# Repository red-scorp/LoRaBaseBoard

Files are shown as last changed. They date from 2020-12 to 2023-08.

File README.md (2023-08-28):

# LoRaBaseBoard

LoRa Base Board for popular Hoperf's RFM95/96/97/98 modules.

One day I wanted to play with LoRa in sender-receiver setup.
What I have fount there are a lot of SMD-mountable modules available but no modules suitable for common prototyping breadboards.
Here I've tried to create a user friendly way to use commonly available LoRa modules.

## LoRaBaseBoard

Simple adapted board intended to be used with variety of RFM LoRa radio modules and being used for HW prototyping.

Preview:

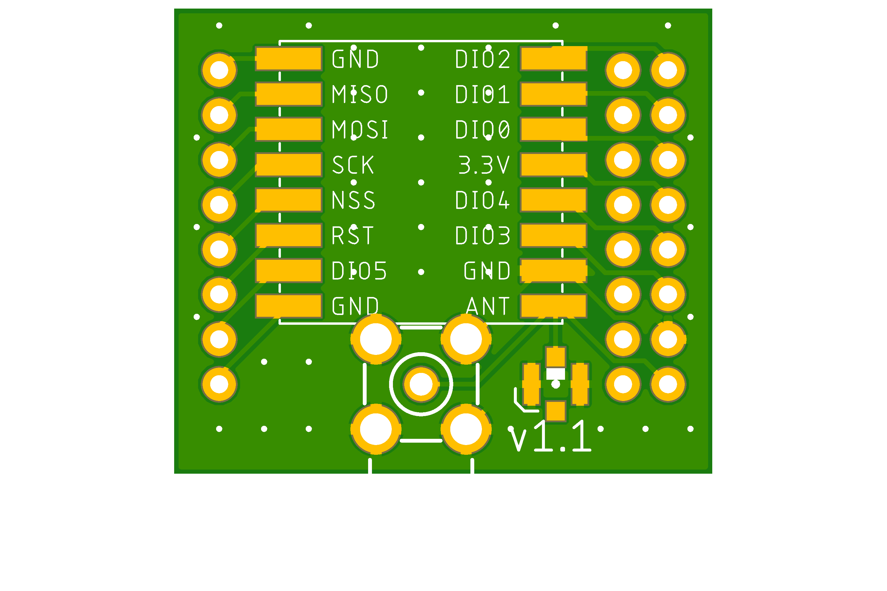
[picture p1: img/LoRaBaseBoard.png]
LoRaBaseBoard preview


[Schematics in PDF format](doc/LoRaBaseBoard.pdf)

Features:

- generic board for RFM radio modules
- compatible with common breadboards and prototyping boards (2.54mm raster)

CAM files are available.

## LoRaAdapter

This adapter board is meant to be a drop-in replacement for NRF24L01 modules.

Preview:

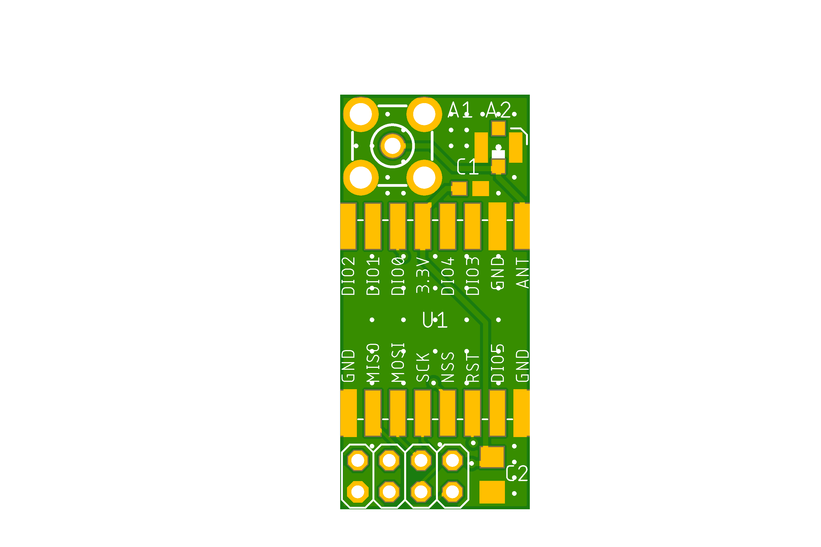
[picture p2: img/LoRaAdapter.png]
LoRaAdapter preview


[Schematics in PDF format](doc/LoRaAdapter.pdf)

Features:

- generic board for RFM95/96/97/98 LoRa radio modules
- compatible with NRF24L01 pinout

CAM files are available.

## BOM

Bill Of Materials is currently available only for LCSC Electronic Components Distributor, which is probably cheapest anyway.

### LCSC BOM

|Designator  |Part/Value  |Package/Footprint |LCSC # |
|---|---|---|---|
|C1 |Cap. 100nF  |0603 |C14663 |
|C2 |Cap. 22uF |1206 |C5672  |
|A1 |SMA conn. | |C496551|
|A2 |U.FL conn.  |SMD |C88374 |

All passive components are optional!

## How to help

Your contributions as code, resources, or finances are welcome! Please contact me directly via email at andriy.golovnya@gmail.com or through my [GitHub profile](https://github.com/red-scorp).

If you'd like to make a financial contribution, you can donate via [PayPal](http://paypal.me/redscorp) or [Ko-Fi](http://ko-fi.com/redscorp). Your support is greatly appreciated.

Thanks in advance!

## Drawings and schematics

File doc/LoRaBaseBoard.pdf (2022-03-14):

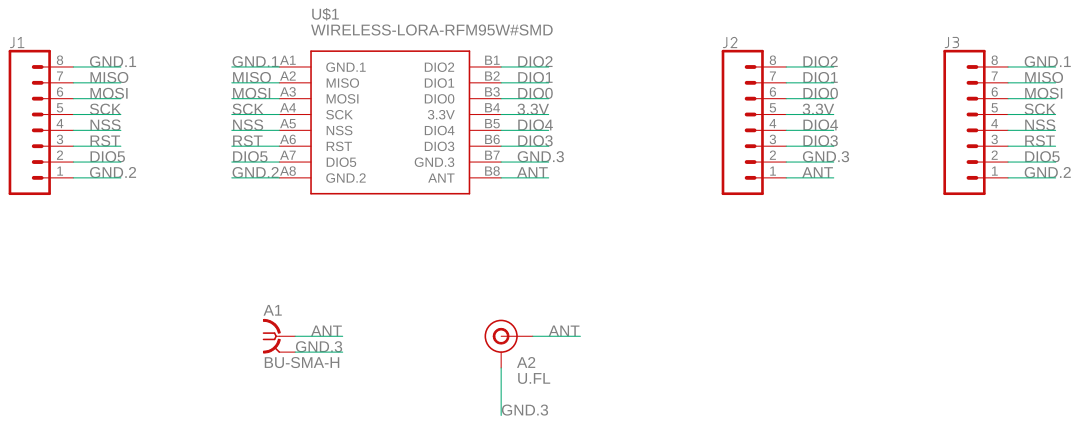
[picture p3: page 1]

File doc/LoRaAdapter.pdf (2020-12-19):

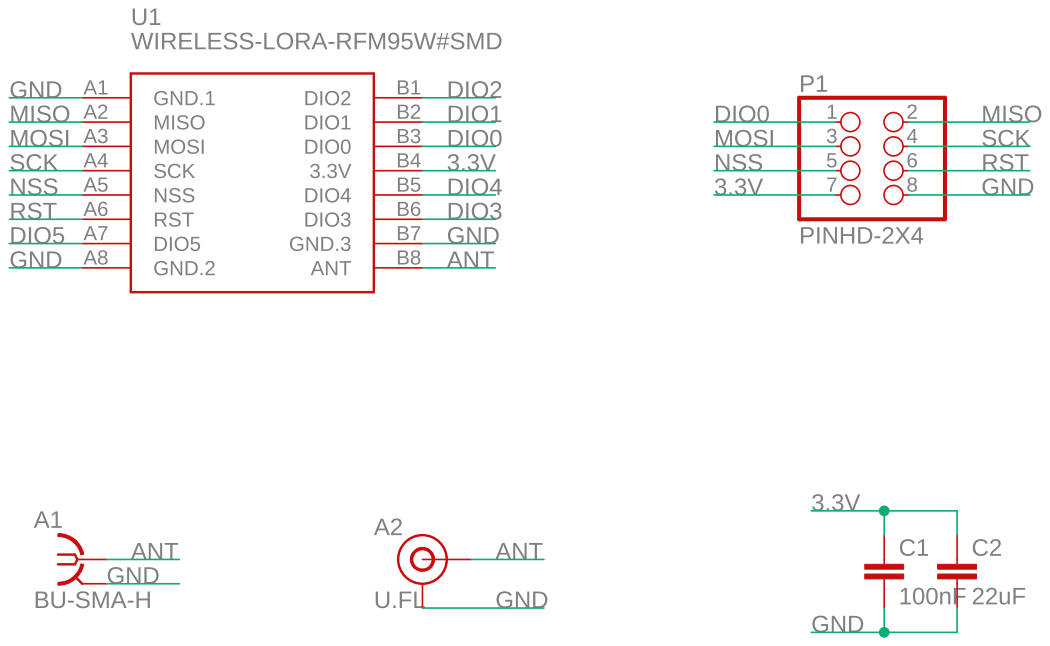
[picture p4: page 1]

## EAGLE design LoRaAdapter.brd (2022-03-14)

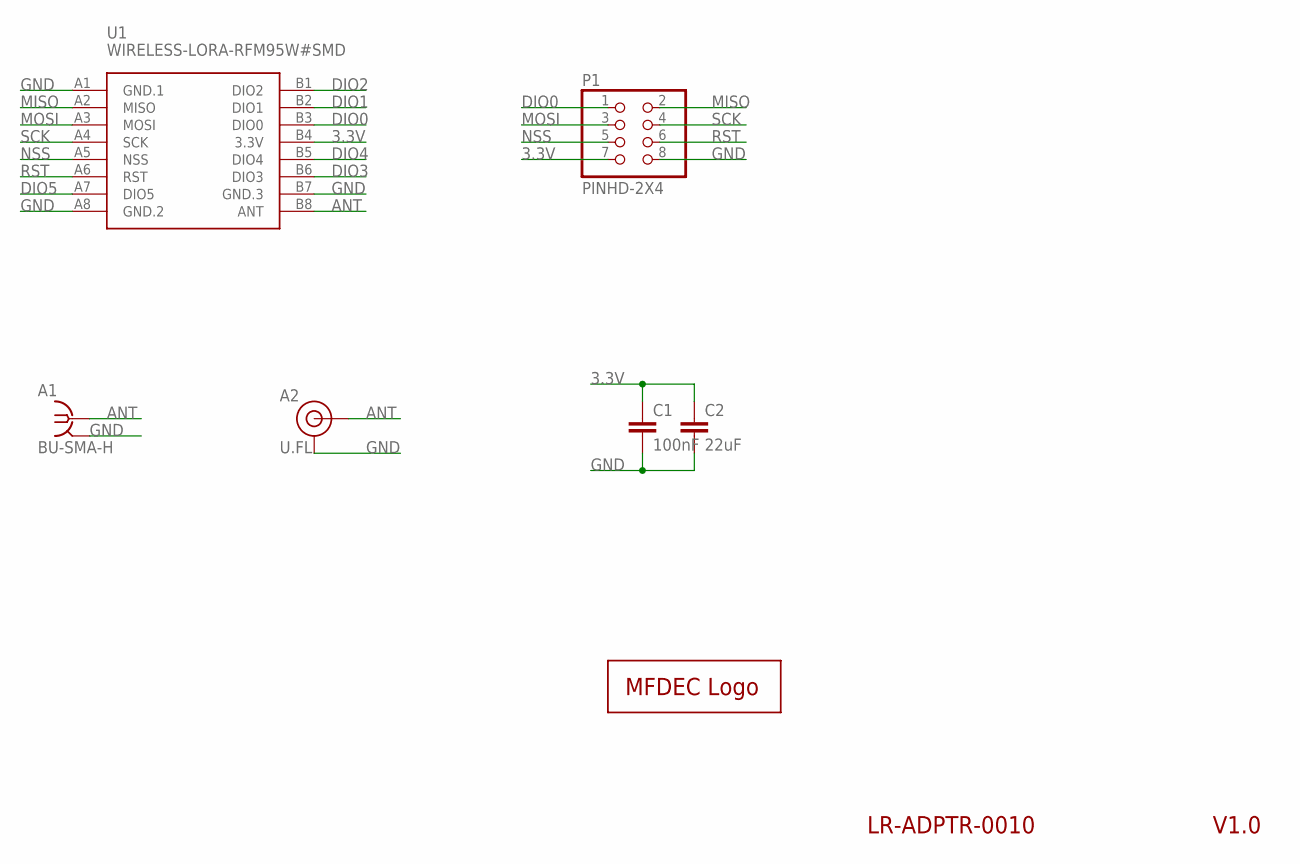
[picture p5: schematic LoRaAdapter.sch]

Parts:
A1: BU-SMA-H
A2: U.FL
C1: 100nF; C0603
C2: 22uF; C1206
LOGO1: MFDECLOGO_SQ_5MM; MFDEC_SQ_5MM
P1: PINHD-2X4; 2X04
U1: WIRELESS-LORA-RFM95W#SMD

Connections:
3.3V: C1.1, C2.1, P1.7, U1.B4 (3.3V)
ANT: A1.1, A2.FEED (SIGNAL), U1.B8 (ANT)
DIO0: P1.1, U1.B3 (DIO0)
DIO1: U1.B2 (DIO1)
DIO2: U1.B1 (DIO2)
DIO3: U1.B6 (DIO3)
DIO4: U1.B5 (DIO4)
DIO5: U1.A7 (DIO5)
GND: A1.2, A1.3 (2), A1.4 (2), A1.5 (2), A2.1 (GND), A2.2 (GND), C1.2, C2.2, P1.8, U1.A1 (GND.1), U1.A8 (GND.2), U1.B7 (GND.3)
MISO: P1.2, U1.A2 (MISO)
MOSI: P1.3, U1.A3 (MOSI)
NSS: P1.5, U1.A5 (NSS)
RST: P1.6, U1.A6 (RST)
SCK: P1.4, U1.A4 (SCK)

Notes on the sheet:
V1.0
LR-ADPTR-0010

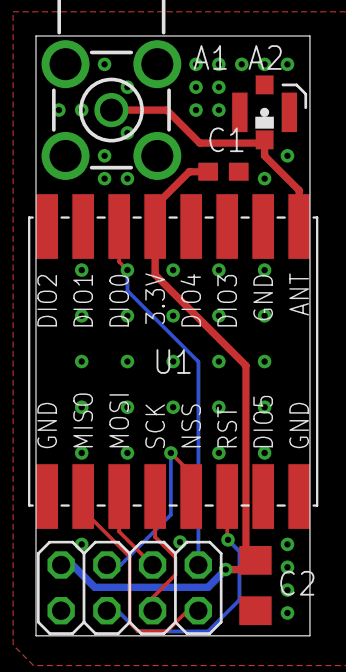
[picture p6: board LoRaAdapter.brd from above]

Board: 2 copper layers, 15.2 x 33.3 mm, 7 parts (1 on the bottom side), 9 nets.

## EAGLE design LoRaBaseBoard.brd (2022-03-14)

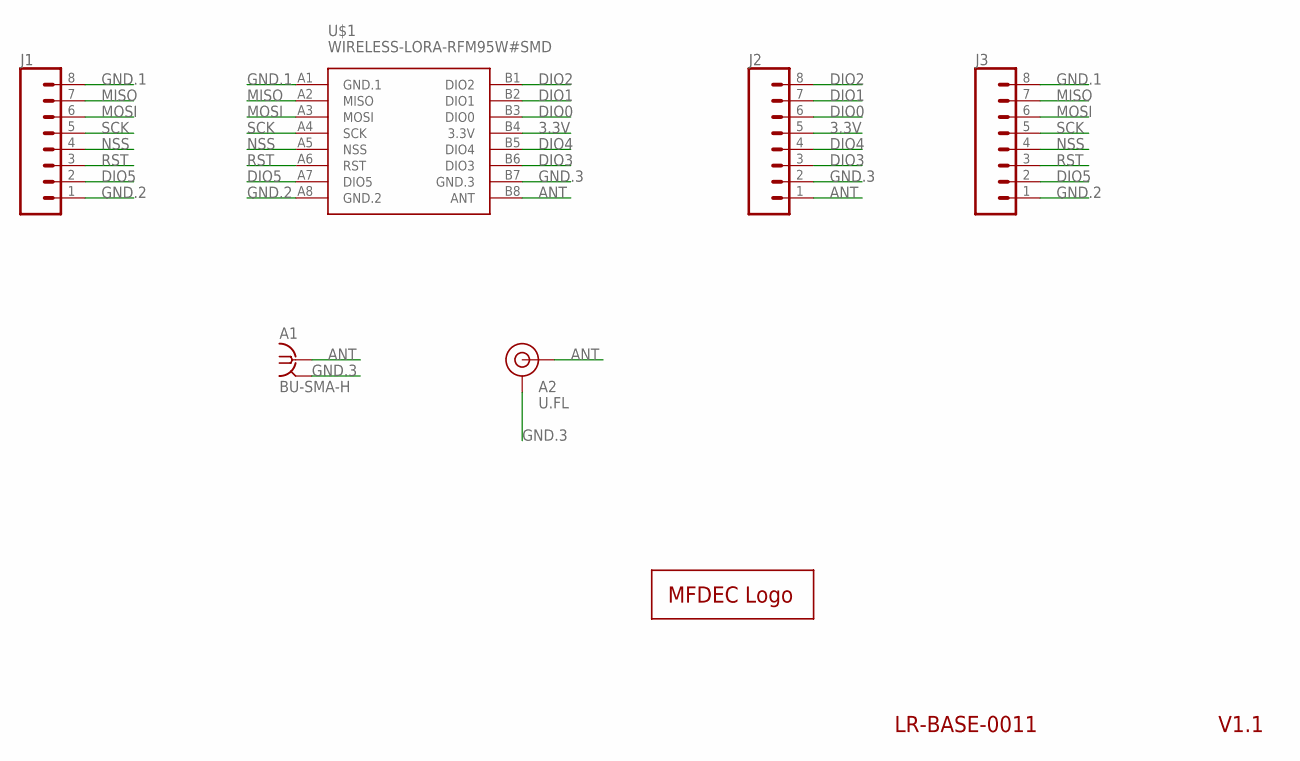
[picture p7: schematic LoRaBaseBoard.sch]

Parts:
A1: BU-SMA-H
A2: U.FL
J1, J2, J3: CONN_08NO_SILK_FEMALE_PTH; 1X08_NO_SILK
LOGO1: MFDECLOGO_SQ_8MM; MFDEC_SQ_8MM
U$1: WIRELESS-LORA-RFM95W#SMD

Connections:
3.3V: J2.5, U$1.B4 (3.3V)
ANT: A1.1, A2.FEED (SIGNAL), J2.1, U$1.B8 (ANT)
DIO0: J2.6, U$1.B3 (DIO0)
DIO1: J2.7, U$1.B2 (DIO1)
DIO2: J2.8, U$1.B1 (DIO2)
DIO3: J2.3, U$1.B6 (DIO3)
DIO4: J2.4, U$1.B5 (DIO4)
DIO5: J1.2, J3.2, U$1.A7 (DIO5)
GND.1: J1.8, J3.8, U$1.A1 (GND.1)
GND.2: J1.1, J3.1, U$1.A8 (GND.2)
GND.3: A1.2, A1.3 (2), A1.4 (2), A1.5 (2), A2.1 (GND), A2.2 (GND), J2.2, U$1.B7 (GND.3)
MISO: J1.7, J3.7, U$1.A2 (MISO)
MOSI: J1.6, J3.6, U$1.A3 (MOSI)
NSS: J1.4, J3.4, U$1.A5 (NSS)
RST: J1.3, J3.3, U$1.A6 (RST)
SCK: J1.5, J3.5, U$1.A4 (SCK)

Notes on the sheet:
V1.1
LR-BASE-0011

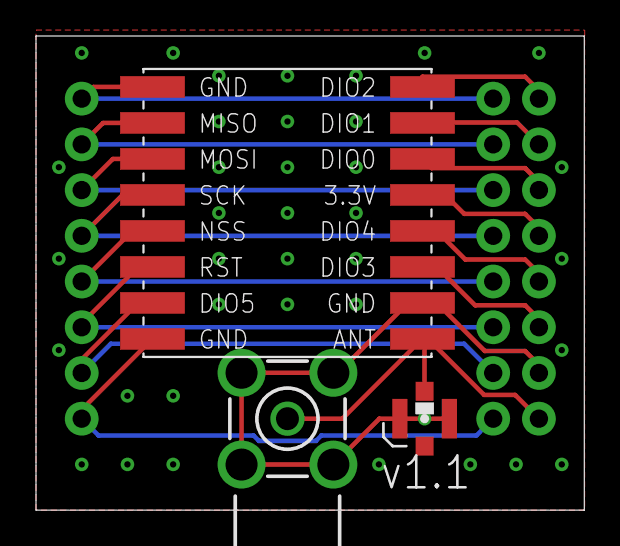
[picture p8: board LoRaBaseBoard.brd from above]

Board: 2 copper layers, 30.5 x 26.3 mm, 7 parts (1 on the bottom side), 16 nets.

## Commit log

2020-09-17 Initial state of the repository
    [LorRaAdapter.brd, LorRaAdapter.sch, LorRaBaseBoard.brd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]
2020-09-19 Add Midnight Fog logos
    [LorRaAdapter.brd, LorRaAdapter.sch, LorRaBaseBoard.brd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]
2020-12-11 Added board ids. Changed some visuals.
    [LorRaAdapter.brd, LorRaAdapter.sch, LorRaBaseBoard.brd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]
2020-12-19 Added PDF schematics.
2020-12-19 Renamed antenna connectors.
    [LorRaBaseBoard.brd, LorRaBaseBoard.sch]
2020-12-19 Renamed files
    [LoRaAdapter.brd, LoRaAdapter.sch, LoRaBaseBoard.brd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]
2020-12-19 Generated new PDF schematics.
2020-12-26 Moved some traces.
    [LoRaAdapter.brd]
2022-03-14 Fixed fill distance. Generated CAM files. Generated PNG preview.
    [LoRaBaseBoard.brd, LoRaBaseBoard.sch]
2022-03-14 Changed soldermask color to green. Generated PNG preview.
    [LoRaAdapter.brd]
2022-03-14 Generated PDF schematics.

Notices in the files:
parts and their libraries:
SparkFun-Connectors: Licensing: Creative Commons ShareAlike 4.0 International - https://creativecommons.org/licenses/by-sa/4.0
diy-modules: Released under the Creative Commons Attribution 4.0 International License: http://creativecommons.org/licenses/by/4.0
